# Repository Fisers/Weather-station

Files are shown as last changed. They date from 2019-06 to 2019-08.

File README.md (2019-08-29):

# Weather Station
## Included sensors
- Wind Direction (NRG #200P)
- Anenometer (NRG #40)
- Humidity (HIH8131)
- Temperature (HIH8131)
- Atmospheric pressure (BMP280)
## Interface methods
- Ethernet TCP
  - Website interface
  - TCP packets to the server
- Nokia 5110 display
- SD card data logging in CSV format
- ~~USB to UART (For debugging and programming with bootloader)~~ See issues #1
## Power supply
- 100V - 240V AC
- 3.3V DC
## Extras
- Real Time Clock
- Easy calibration using buttons
- Space Invaders minigame
- No easter eggs
## Free PINs for future upgrades
- PB0 (Timer 0) | PA3 (ADC) | PA4 (ADC) | PA5 (ADC) | PA6 (ADC) | PA7 (ADC)
- Motherboard also has free connections to 3.3v and GND aswell as SPI.

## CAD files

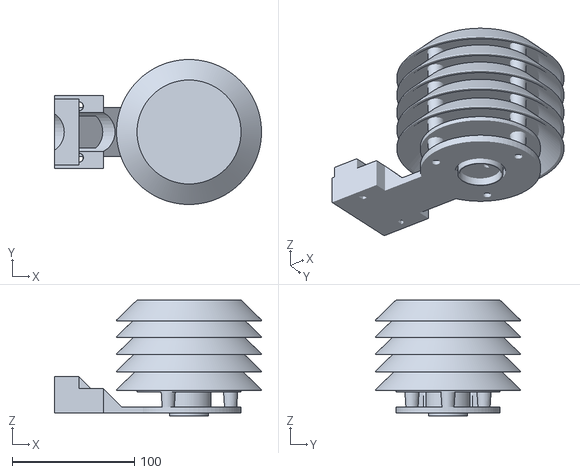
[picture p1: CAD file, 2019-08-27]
hardware/Radiation shield/Daniels_Assembled.stl
169.3 x 118.5 x 94.8

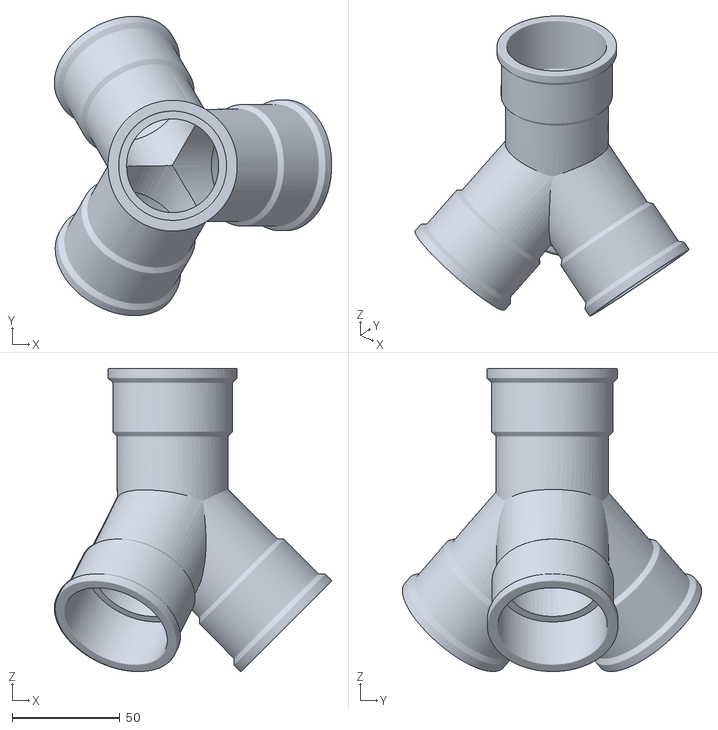
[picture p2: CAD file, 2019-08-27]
hardware/PVC tripod/tripod.stl
128.9 x 139.1 x 140.8

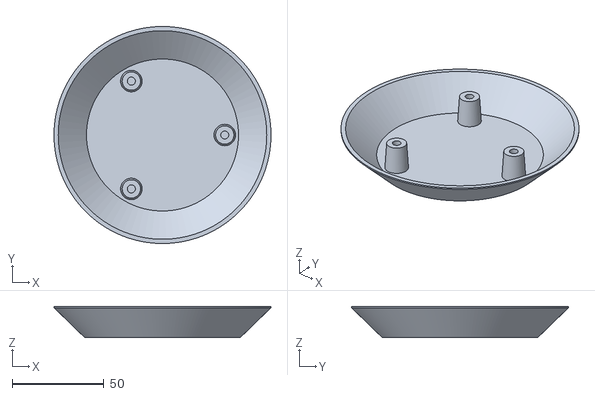
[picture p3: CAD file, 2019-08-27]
hardware/Radiation shield/Rad_Shd_Top_V1.stl
118.5 x 118.5 x 17.0

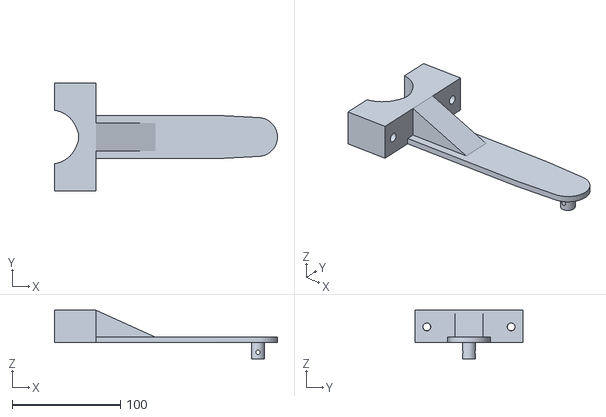
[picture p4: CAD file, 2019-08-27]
hardware/sensor mount/sensor mount.stl
206.3 x 100.0 x 45.0

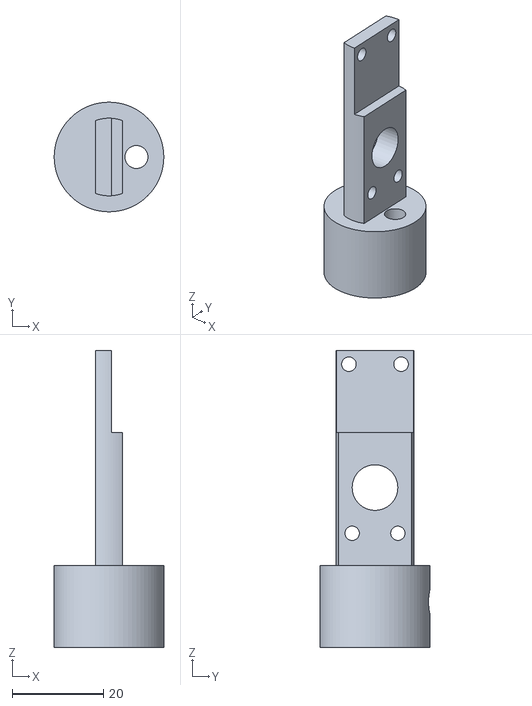
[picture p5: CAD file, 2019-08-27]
hardware/Radiation shield/HTU21D_mount_V1.stl
24.0 x 24.0 x 65.0

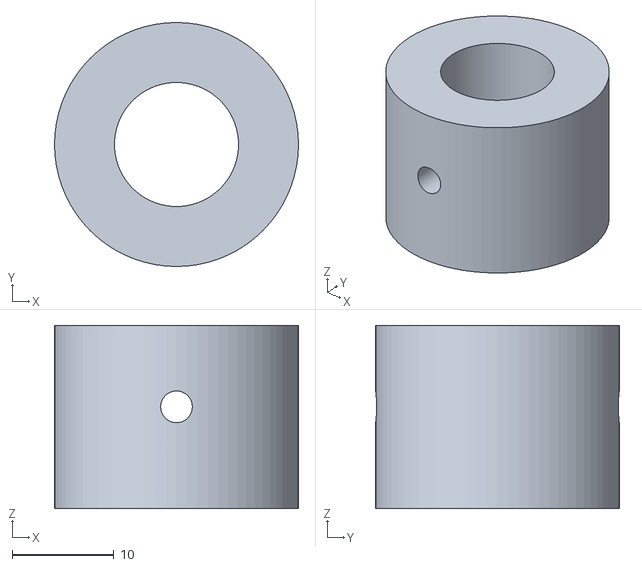
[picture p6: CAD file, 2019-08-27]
hardware/Radiation shield/HTM2500_mount_V1.stl
24.0 x 24.0 x 18.0

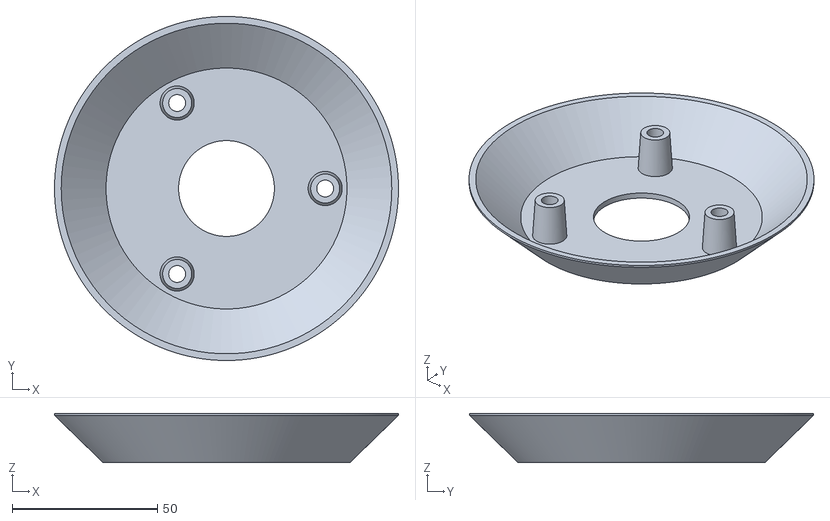
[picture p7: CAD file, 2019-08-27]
hardware/Radiation shield/Rad_Shd_Fin_V1.stl
118.5 x 118.5 x 17.0

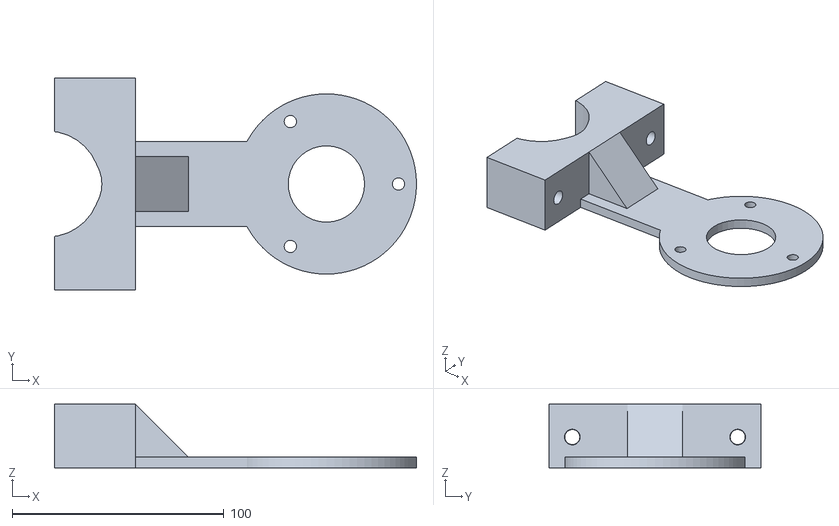
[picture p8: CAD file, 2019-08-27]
hardware/Radiation shield/Daniels_Base_Holder.stl
170.8 x 100.0 x 30.0

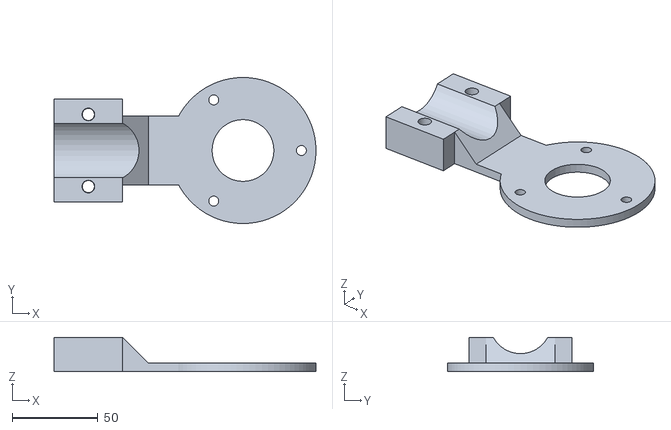
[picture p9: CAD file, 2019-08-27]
hardware/Radiation shield/Rad_Shd_Horz_mount_V1.stl
152.5 x 85.0 x 20.0

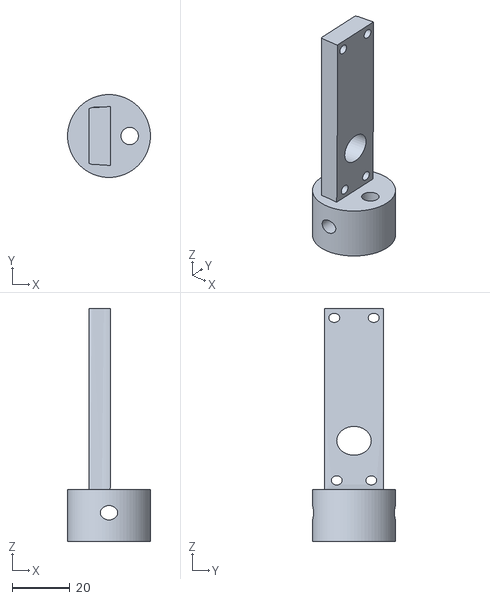
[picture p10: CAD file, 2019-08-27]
hardware/Radiation shield/Daniels_Mount.stl
28.8 x 28.8 x 81.0

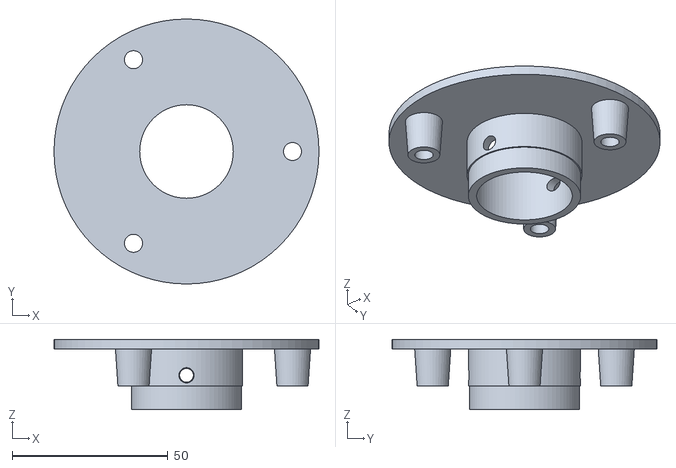
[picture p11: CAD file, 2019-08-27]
hardware/Radiation shield/Daniels_Base.stl
85.0 x 85.0 x 22.5

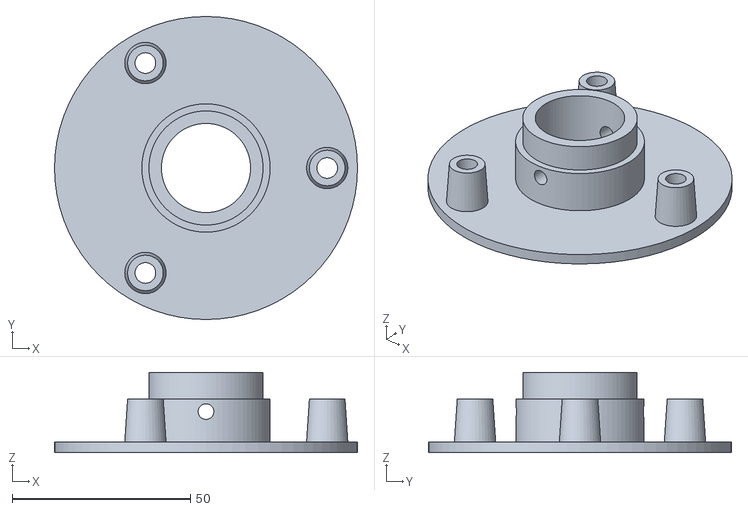
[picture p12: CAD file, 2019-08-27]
hardware/Radiation shield/Rad_Shd_Base_V1.stl
85.0 x 85.0 x 22.5

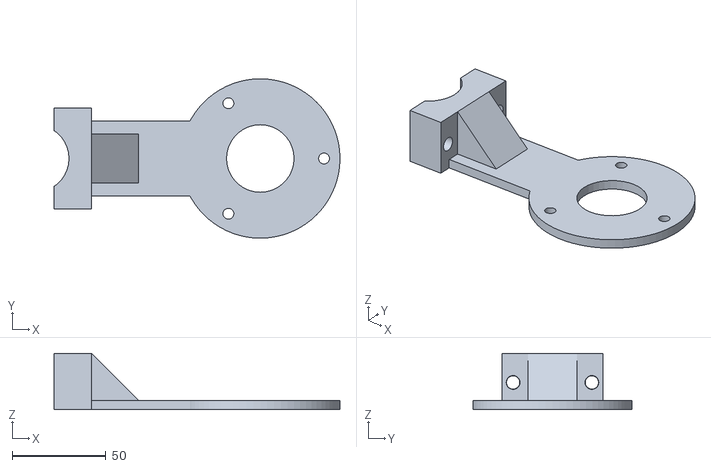
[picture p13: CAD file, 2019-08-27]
hardware/Radiation shield/Rad_Shd_Vert_mount_V1.stl
152.5 x 85.0 x 30.0

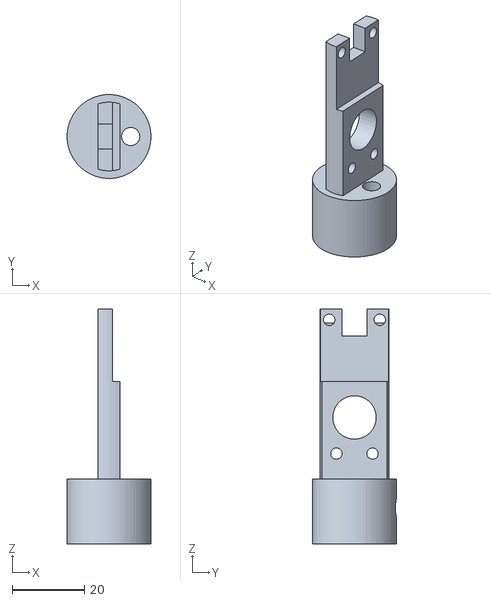
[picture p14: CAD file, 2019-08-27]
hardware/Radiation shield/SHT15_mount_V1.stl
23.2 x 23.2 x 65.0

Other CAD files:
hardware/Radiation shield/AM2315_mount_V1.stl
hardware/Radiation shield/Daniels_Base_Clamp.stl
hardware/PVC tripod/tripod.blend
hardware/Radiation shield/Radiation shield.blend
hardware/sensor mount/sensor mount.blend

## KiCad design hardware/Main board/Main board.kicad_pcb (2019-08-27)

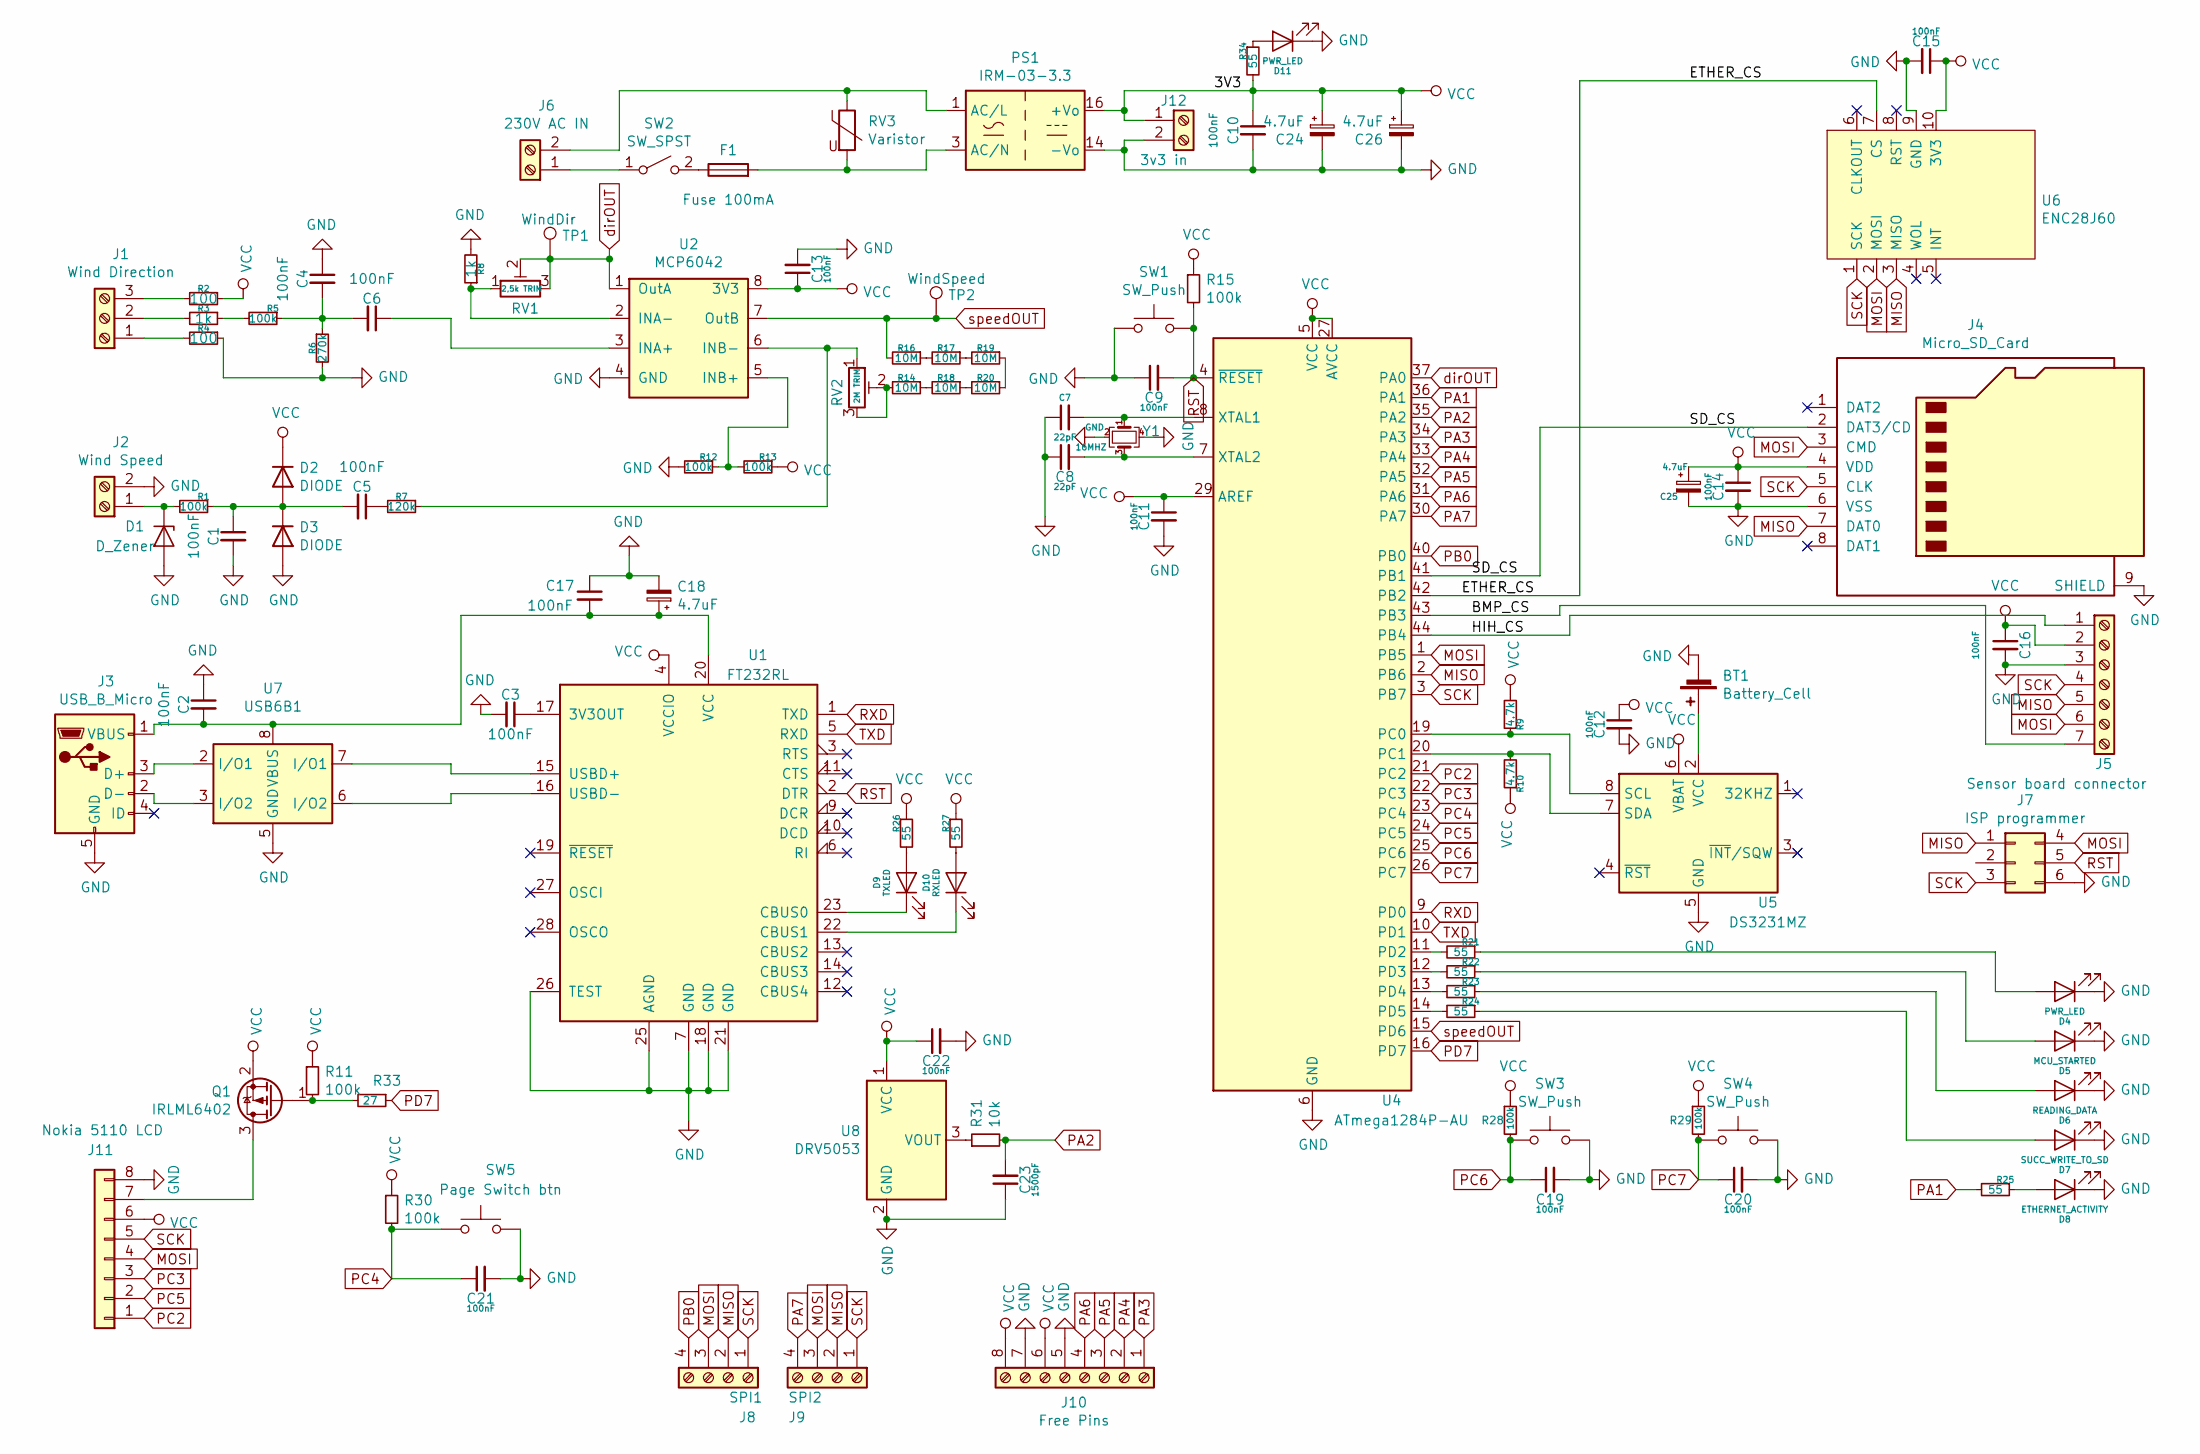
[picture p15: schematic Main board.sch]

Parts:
BT1: Battery_Cell; BatteryHolder_Keystone_106_1x20mm
C1, C2, C3, C4, C5, C6, C9, C10, C11, C12, C13, C14, C15, C16, C17, C19, C20, C21, C22: 100nF; C_0805_2012Metric_Pad1.15x1.40mm_HandSolder
C7, C8: 22pF; C_0805_2012Metric_Pad1.15x1.40mm_HandSolder
C18: 4.7uF; CP_Elec_4x5.3
C23: 1500pF; C_0805_2012Metric_Pad1.15x1.40mm_HandSolder
C24, C25, C26: 4.7uF; CP_Elec_4x5.4
D1: D_Zener; D_0805_2012Metric
D2, D3: DIODE; D_0805_2012Metric
D4, D11: PWR_LED; D_0805_2012Metric
D5: MCU_STARTED; D_0805_2012Metric
D6: READING_DATA; D_0805_2012Metric
D7: SUCC_WRITE_TO_SD; D_0805_2012Metric
D8: ETHERNET_ACTIVITY; D_0805_2012Metric
D9: TXLED; D_0805_2012Metric
D10: RXLED; D_0805_2012Metric
F1: Fuse 100mA; Fuseholder_Cylinder-5x20mm_Schurter_0031_8201_Horizontal_Op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
J1: Wind Direction; TerminalBlock_Altech_AK300-4_P5.00mm
J2: Wind Speed; TerminalBlock_Altech_AK300-2_P5.00mm
J3: USB_B_Micro; KYCON_KMMVX-SMT-BS-BTR
J4: Micro_SD_Card; microSD
J5: Sensor board connector; TerminalBlock_Phoenix_MKDS-1,5-8_1x08_P5.00mm_Horizontal
J6: 230V AC IN; TerminalBlock_RND_205-00298_1x02_P10.00mm_Horizontal
J7: ISP programmer; PinHeader_2x03_P2.54mm_Vertical
J8: SPI1; TerminalBlock_Altech_AK300-4_P5.00mm
J9: SPI2; TerminalBlock_Altech_AK300-4_P5.00mm
J10: Free Pins; TerminalBlock_Phoenix_MKDS-1,5-8_1x08_P5.00mm_Horizontal
J11: Nokia 5110 LCD; Nokia_5110_LCD
J12: 3v3 in; TerminalBlock_Altech_AK300-2_P5.00mm
PS1: IRM-03-3.3; Converter_ACDC_MeanWell_IRM-03-xx_THT
Q1: IRLML6402; SOT-23
R1, R5, R11, R12, R13, R15, R28, R29, R30: 100k; R_0805_2012Metric
R2, R4: 100; R_0805_2012Metric
R3, R8: 1k; R_0805_2012Metric
R6: 270k; R_0805_2012Metric
R7: 120k; R_0805_2012Metric
R9, R10: 4.7k; R_0805_2012Metric
R14, R16, R17, R18, R19, R20: 10M; R_0805_2012Metric
R21, R22, R23, R24, R25, R26, R27, R34: 55; R_0805_2012Metric
R31: 10k; R_0805_2012Metric
R33: 27; R_0805_2012Metric
RV1: 2,5k TRIM; Potentiometer_Bourns_3314G_Vertical
RV2: 2M TRIM; Potentiometer_Bourns_3224W_Vertical
RV3: Varistor; Varistor_SMD
SW1, SW3, SW4: SW_Push; SW_Push_1P1T_NO_6x6mm_H9.5mm
SW2: SW_SPST; Switch_NEW
SW5: Page Switch btn; SW_Push_1P1T_NO_6x6mm_H9.5mm
TP1: WindDir; Test_Pad
TP2: WindSpeed; Test_Pad
U1: FT232RL; SSOP-28_5.3x10.2mm_P0.65mm
U2: MCP6042; MCP6042-E&slash_P
U4: ATmega1284P-AU; TQFP-44_10x10mm_P0.8mm
U5: DS3231MZ; SOIC-8_3.9x4.9mm_P1.27mm
U6: ENC28J60
U7: USB6B1; SOIC-8_3.9x4.9mm_P1.27mm
U8: DRV5053; PinSocket_1x03_P2.54mm_Vertical
Y1: 16MHZ; Crystal_SMD

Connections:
/BMP_CS: J5.7, U4.43 (PB3)
/ETHER_CS: U4.42 (PB2), U6.7 (CS)
/HIH_CS: J5.1, U4.44 (PB4)
/SD_CS: J4.2 (DAT3/CD), U4.41 (PB1)
GND: BT1.2 (-), C1.2, C2.1, C3.2, C4.1, C7.1, C8.1, C9.1, C10.2, C11.2, C12.2, C13.2, C14.2, C15.2, C16.2, C17.1, C18.2, C19.2, C20.2, C21.2, C22.2, C23.1, C24.2, C25.2, C26.2, D1.2 (A), D3.1 (A), D4.1 (K), D5.1 (K), D6.1 (K), D7.1 (K), D8.1 (K), D11.1 (K), J2.2, J3.5 (GND), J4.6 (VSS), J4.9 (SHIELD), J5.3, J7.6, J10.5, J10.7, J11.8, J12.2, PS1.14 (-Vo), R4.1, R6.2, R8.2, R12.2, SW1.1, SW3.2, SW4.2, SW5.2, U1.7 (GND), U1.18 (GND), U1.21 (GND), U1.25 (AGND), U1.26 (TEST), U2.4 (GND), U4.6 (GND), U4.18 (GND), U4.28 (GND), U4.39 (GND), U5.5 (GND), U6.9 (GND), U7.4 (GND), U7.5 (GND), U8.2 (GND), Y1.2, Y1.4
MISO: J4.7 (DAT0), J5.5, J7.1, J8.2, J9.2, U4.2 (PB6), U6.3 (MISO)
MOSI: J4.3 (CMD), J5.6, J7.4, J8.3, J9.3, J11.4, U4.1 (PB5), U6.2 (MOSI)
unnamed: BT1.1 (+), U5.2 (VCC)
unnamed: C1.1, C5.2, D2.1 (A), D3.2 (K), R1.1
unnamed: C3.1, U1.17 (3V3OUT)
unnamed: C4.2, C6.2, R5.1, R6.1
unnamed: C5.1, R7.2
unnamed: C6.1, U2.3 (INA+)
unnamed: C7.2, U4.8 (XTAL1), Y1.1
unnamed: C8.2, U4.7 (XTAL2), Y1.3
unnamed: C2.2, C17.2, C18.1, J3.1 (VBUS), U1.20 (VCC), U7.1 (VBUS), U7.8 (VBUS)
unnamed: D1.1 (K), J2.1, R1.2
unnamed: D4.2 (A), R21.1
unnamed: D5.2 (A), R22.1
unnamed: D6.2 (A), R23.1
unnamed: D7.2 (A), R24.1
unnamed: D8.2 (A), R25.1
unnamed: D9.1 (K), U1.23 (CBUS0)
unnamed: D9.2 (A), R26.2
unnamed: D10.1 (K), U1.22 (CBUS1)
unnamed: D10.2 (A), R27.2
unnamed: D11.2 (A), R34.1
unnamed: F1.1, SW2.2 (B)
unnamed: F1.2, PS1.3 (AC/N), RV3.2
unnamed: J1.1, R4.2
unnamed: J1.2, R3.2
unnamed: J1.3, R2.2
unnamed: J3.2 (D-), U7.3 (I/O2)
unnamed: J3.3 (D+), U7.2 (I/O1)
unnamed: J6.1, SW2.1 (A)
unnamed: J6.2, PS1.1 (AC/L), RV3.1
unnamed: J11.7, Q1.3 (D)
unnamed: Q1.1 (G), R11.2, R33.2
unnamed: R3.1, R5.2
unnamed: R7.1, RV2.1, U2.6 (INB-)
unnamed: R8.1, RV1.1, U2.2 (INA-)
unnamed: R9.1, U4.19 (PC0), U5.8 (SCL)
unnamed: R10.2, U4.20 (PC1), U5.7 (SDA)
unnamed: R12.1, R13.2, U2.5 (INB+)
unnamed: R14.1, R18.2
unnamed: R14.2, RV2.2, RV2.3
unnamed: R16.1, R17.2
unnamed: R17.1, R19.2
unnamed: R18.1, R20.2
unnamed: R19.1, R20.1
unnamed: R21.2, U4.11 (PD2)
unnamed: R22.2, U4.12 (PD3)
unnamed: R23.2, U4.13 (PD4)
unnamed: R24.2, U4.14 (PD5)
unnamed: R31.1, U8.3 (VOUT)
unnamed: U1.15 (USBD+), U7.7 (I/O1)
unnamed: U1.16 (USBD-), U7.6 (I/O2)
PA1: R25.2, U4.36 (PA1)
PA2: C23.2, R31.2, U4.35 (PA2)
PA3: J10.1, U4.34 (PA3)
PA4: J10.2, U4.33 (PA4)
PA5: J10.3, U4.32 (PA5)
PA6: J10.4, U4.31 (PA6)
PA7: J9.4, U4.30 (PA7)
PB0: J8.4, U4.40 (PB0)
PC2: J11.1, U4.21 (PC2)
PC3: J11.3, U4.22 (PC3)
PC4: C21.1, R30.2, SW5.1, U4.23 (PC4)
PC5: J11.2, U4.24 (PC5)
PC6: C19.1, R28.2, SW3.1, U4.25 (PC6)
PC7: C20.1, R29.2, SW4.1, U4.26 (PC7)
PD7: R33.1, U4.16 (PD7)
RST: C9.2, J7.5, R15.2, SW1.2, U1.2 (DTR), U4.4 (~RESET)
RXD: U1.1 (TXD), U4.9 (PD0)
SCK: J4.5 (CLK), J5.4, J7.3, J8.1, J9.1, J11.5, U4.3 (PB7), U6.1 (SCK)
TXD: U1.5 (RXD), U4.10 (PD1)
VCC: C10.1, C11.1, C12.1, C13.1, C14.1, C15.1, C16.1, C22.1, C24.1, C25.1, C26.1, D2.2 (K), J4.4 (VDD), J5.2, J10.6, J10.8, J11.6, J12.1, PS1.16 (+Vo), Q1.2 (S), R2.1, R9.2, R10.1, R11.1, R13.1, R15.1, R26.1, R27.1, R28.1, R29.1, R30.1, R34.2, U1.4 (VCCIO), U2.8 (3V3), U4.5 (VCC), U4.17 (VCC), U4.27 (AVCC), U4.29 (AREF), U4.38 (VCC), U5.6 (VBAT), U6.10 (3V3), U8.1 (VCC)
dirOUT: RV1.2, RV1.3, TP1.1, U2.1 (OutA), U4.37 (PA0)
speedOUT: R16.2, TP2.1, U2.7 (OutB), U4.15 (PD6)

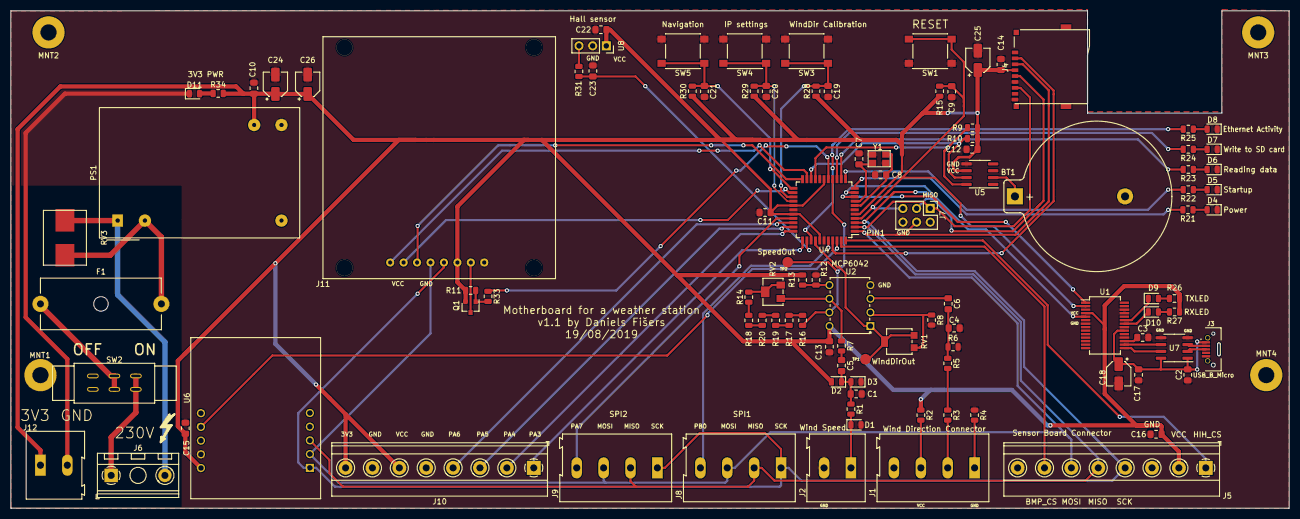
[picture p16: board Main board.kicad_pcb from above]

Board: 2 copper layers, 237.8 x 92.5 mm, 108 parts (0 on the bottom side), 79 nets.

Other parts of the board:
MNT1, MNT2, MNT3, MNT4: MountingHole_3mm_Pad

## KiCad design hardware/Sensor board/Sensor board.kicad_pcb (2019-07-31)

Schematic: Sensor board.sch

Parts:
C1, C2: C_Small; C_0805_2012Metric_Pad1.15x1.40mm_HandSolder
J1: Conn_01x07_Female; PinSocket_1x07_P2.54mm_Vertical
J2: bmp280; PinSocket_1x07_P2.54mm_Vertical
R1: R_Small; R_0805_2012Metric_Pad1.15x1.40mm_HandSolder
U1: HIH8130; SOIC-8_3.9x4.9mm_P1.27mm

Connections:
/BMP280_CS: J1.7, J2.7
/CLK: J1.4, J2.4, U1.4
/MISO: J1.5, J2.5, U1.5
/MOSI: J1.6, J2.6
GND: C1.1, C2.1, J1.3, J2.3, U1.2
unnamed: C2.2, U1.1
unnamed: J1.1, R1.2, U1.3
VCC: C1.2, J1.2, J2.2, R1.1, U1.8

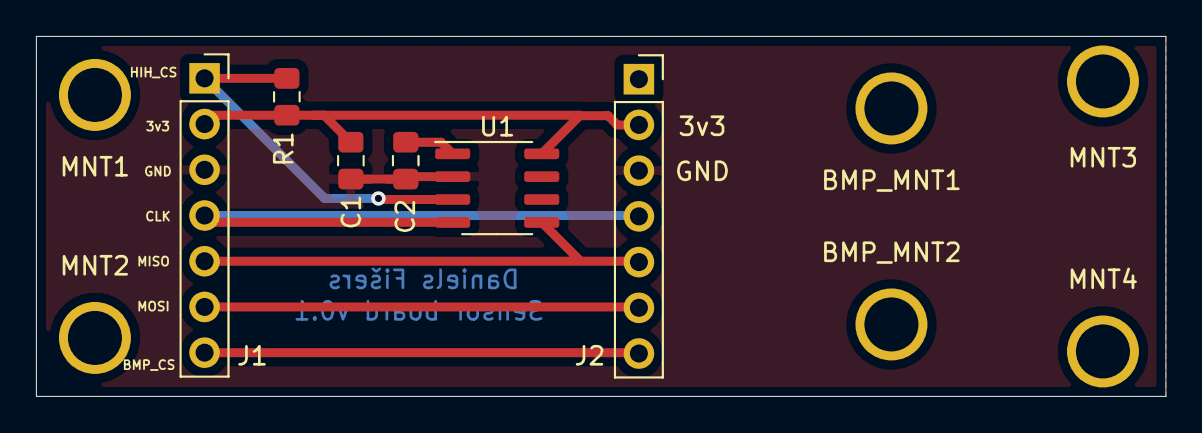
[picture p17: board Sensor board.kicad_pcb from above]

Board: 2 copper layers, 62.8 x 20.0 mm, 12 parts (0 on the bottom side), 8 nets.

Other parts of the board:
BMP_MNT1, BMP_MNT2: MountingHole_3mm_Pad
MNT1, MNT2, MNT3, MNT4: MountingHole_3mm_Pad

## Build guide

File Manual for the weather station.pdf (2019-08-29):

# Manual for the weather station

## Startup sequence

1. | 2. | 3. | 4. | 5.
All LEDs flash together to test for any bad ones. | The power LED stays on. Sensor init. | Check for any buttons pressed. | Mounting the SD card (Write to SD card LED flashes). | Connecting to the ethernet shield (Ethernet activity LED turns on while connecting).

## Calibrating wind direction ADC sensor

1. Press the WindDir Calibration button and then the RESET button.
2. Release the RESET button but keep holding the WindDir Calibration button until the display says the calibration started.
3. The display will show the current analog value, to calibrate the sensor, it has to be spun in a clockwise direction. (The value on the display should increase and startup LED blink while spinning).

## Changing Ethernet settings via serial port

1. Connect the computer to the weather station using USB and enable a serial terminal. (baud rate: 9600)
2. Press the IP settings button and then the RESET button.
3. Release the RESET button but keep holding the IP settings button until the display says the calibration started.
4. Follow instructions in the serial terminal and type IPs in format: xxx.xxx.xxx.xxx\n (example: 192.168.0.101\n)

## Web interface

- First-page displays information from sensors as well as if the box is open.
- IP settings can be changed in the settings page, as well as the port to send data to.
- The timeout (how often the data is sent) can also be changed. Timeout is the time weather station spends in the Ethernet state.
- Hall sensor value is the threshold at which it detects if the box is closed. (Try to lower the value if after closing the box it is still indicated as open, and check if the sensor is in place as well as the magnet).
- RTC Settings page is used to set the current date and time.

## Changing brightness of LCD display

To lower brightness: Hold IP Settings button and press Navigation button. To increase brightness: Hold WindDir Calibration button and press Navigation button.

## Space Invaders mode

- To start Space Invaders hold the Navigation button and WindDir Calibration button and press the RESET button. Hold them until Space Invaders splash screen appears on the display.
- Controls:
- Left - Navigation button.
- Shoot - IP Settings button.
- Right - WindDir Calibration button.
- In game mode, data won’t be collected!
- After 24 seconds of not pressing any buttons, the weather station will be reset into normal mode.

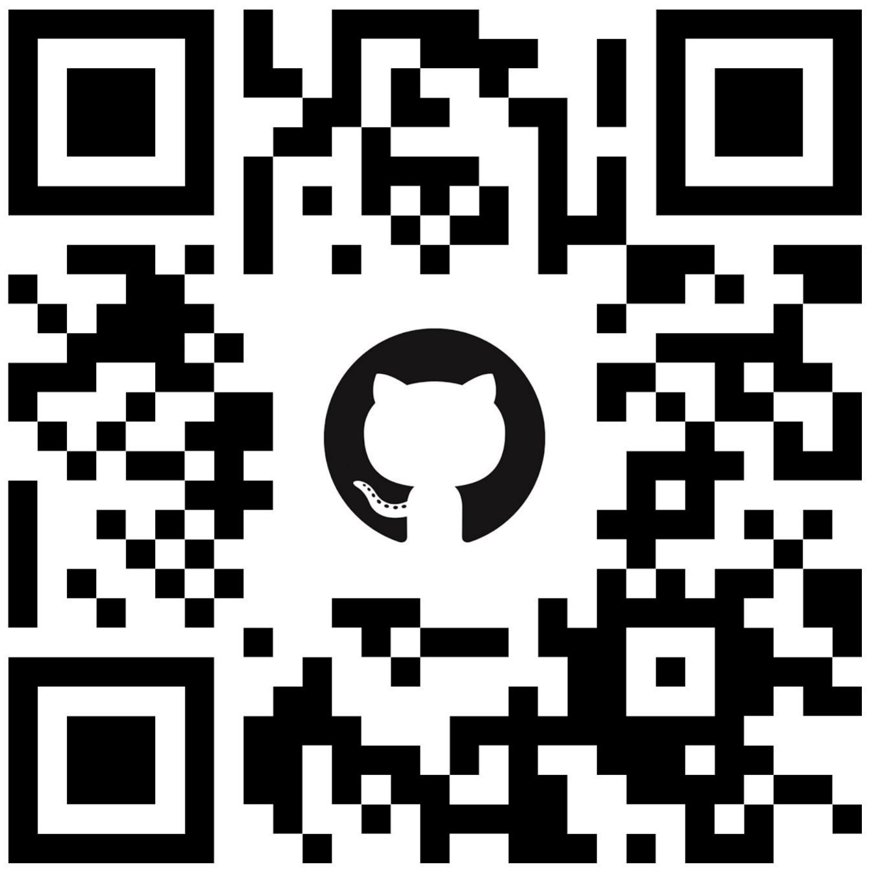
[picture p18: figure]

GitHub: https://github.com/Fisers/meteostacija | By Daniels Fišers

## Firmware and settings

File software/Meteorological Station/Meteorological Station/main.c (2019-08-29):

#define F_CPU 16000000UL // Defining the CPU Frequency for Delay Calculation in delay.h
#define BAUD 9600

#include <stdlib.h>
#include <avr/io.h> // Contains all the I/O Register Macros
#include <avr/eeprom.h>
#include <avr/pgmspace.h>
#include <avr/interrupt.h>
#include <util/delay.h> // Generates a Blocking Delay
#include <stdio.h>
#include <string.h>
#include <ctype.h>
#include "main.h"
#include <avr/wdt.h>
#include "Options.h"
#include "includes/SpaceInvaders/Space.h"



// Function Pototype
void wdt_init(void) __attribute__((naked)) __attribute__((section(".init3")));


// Function Implementation
void wdt_init(void)
{
	MCUSR = 0;
	wdt_disable();

	return;
}

// FatFs
FATFS FatFs;
FIL Fil;

UINT bw;
//
unsigned int magnetVal;
unsigned int halleff = 550;
unsigned int timeout;
rtc_t rtc;
int8_t gameMode = 0;

int brightness = 128;

static void initADC()
{
	ADCSRA |= (1 << ADEN) | (1 << ADPS2) | (1 << ADPS1) | (1 << ADPS0);
	ADMUX |= (1 << REFS0) | (1 << MUX1);
}

#define REF_AVCC (1<<REFS0)  // reference = AVCC = 3.3 V
uint16_t adc_read(uint8_t channel)
{
	ADMUX = REF_AVCC | channel;  // set reference and channel
	ADCSRA |= (1<<ADSC);         // start conversion
	while(ADCSRA & (1<<ADSC)); // wait for conversion complete
	return ADC;
}

int16_t LargestDirectionValue;
static void calibration()
{
	printf_P(PSTR("Calibration started!\n"));
	lcd_setXY(0x40,0x80);
	N5110_Data("Calibration");
 	lcd_setXY(0x41,0x80);
 	N5110_Data("Started");
	while(adc_read(0)+50 >= LargestDirectionValue)
	{
		wdt_reset();
		if(adc_read(0) > LargestDirectionValue)
		{
			PORTD |= (1 << PIND3);
			LargestDirectionValue = adc_read(0);
			dtostrf(LargestDirectionValue,1,2,pressChar);
			lcd_setXY(0x43,0x80);
			N5110_Data(pressChar);
		}
		_delay_us(250);
		PORTD &= ~(1 << PIND3);
	}
	eeprom_write_float(0x00, LargestDirectionValue);
	printf_P(PSTR("Calibration complete!\n"));
}

void stringToIntArray(uint8_t * array, char * string, uint8_t * eepromAddr)
{
	uint8_t i = 0;
	char * p = string;
	while(*p) {
		if ( isdigit(*p) || ( (*p=='-'||*p=='+') && isdigit(*(p+1)) )) {
			array[i] = strtol(p, &p, 10);
			eeprom_write_byte((uint8_t*)eepromAddr+i, array[i]);
			i++;
			} else {
			p++;
		}
	}
}

static void getInput(char *input)
{
	char c;
	uint8_t i;
	for(i = 0; i < 16; i++) {
		c = getchar();
		if (c == '\n') break;
		input[i] = c;
	}
	input[i] = '\0';
}

static void ipconfig()
{
	static char input[16];
	
	lcd_setXY(0x40,0x80);
	N5110_Data("Calibration");
	lcd_setXY(0x41,0x80);
	N5110_Data("Started");

	puts("Input arduino IP");
	getInput(input);
	printf("Arduino IP: %s\n", input);
	stringToIntArray(myip, input, (uint8_t*)0x20);
	
	puts("Input server IP");
	getInput(input);
	printf("Server IP: %s\n", input);
	sprintf(serverip, "%s", input);
	eeprom_write_block((const void*)input, (void*)0x30, 16);
	
	puts("Input gateway IP");
	getInput(input);
	printf("Gateway IP: %s\n", input);
	stringToIntArray(gwip, input, (uint8_t*)0x40);
}

char packetStr[128];
uint8_t runOnce = 0;
char humidChar[10],tempChar[10],pressChar[16],anglChar[10],speedChar[10];
int page = 1;

ISR(PCINT2_vect)
{
	if((PINC&(1 << PINC4)) == 0)
	{
		if((PINC&(1 << PINC7)) == 0)
		{
			if(brightness + 25 > 255)
			{
				brightness = 255;
			}
			else
			{
				brightness += 25;
			}
		}
		else if((PINC&(1 << PINC6)) == 0)
		{
			if(brightness - 25 < 0)
			{
				brightness = 0;
			}
			else
			{
				brightness -= 25;
			}
		}
		else
		{
			page++;
			if(page >= 4) page = 1;
		
			printPage(page);
		}
		OCR2A = brightness;
		TCCR2A |= (1 << COM2A1);
		TCCR2A |= (1 << WGM21) | (1 << WGM20);
		TCCR2B |= (1 << CS21);
	}
}

int main(void)
{	
	// init arrays
	//memset(bullets, 0, 32);
	//
 	DDRD = 0b10111100;
 	DDRA |= (1 << PINA1);
	PORTA |= (1 << PINA1);
	PORTD = 0b00111100;
	_delay_ms(500);
 	PORTD &= 0b11000111;
 	PORTA &= ~(1 << PINA1);
	PORTD &= ~(1 << PIND5);
	
	
	
 	

// 	uart_init();
// 	stdout = &uart_output;
// 	stdin  = &uart_input;
// 	puts_P(PSTR("Initializing"));
 	DDRC |= (0 << PINC6);
 	PORTC |= (1 << PINC6);
	DDRC |= (0 << PINC7);
	PORTC |= (1 << PINC7);
	DDRC |= (0 << PINC4);
	PORTC |= (1 << PINC4);
	
	 DDRD |= (1 << DDD7);
	 // PD6 is now an output

	 OCR2A = brightness;
	 // set PWM for 50% duty cycle


	 TCCR2A |= (1 << COM2A1);
	 // set none-inverting mode

	 TCCR2A |= (1 << WGM21) | (1 << WGM20);
	 // set fast PWM Mode

	 TCCR2B |= (1 << CS21);
	 // set prescaler to 8 and starts PWM
	 
	spi_init_master();
 	N5110_init();
	N5110_clear();
	
	DDRD |= (1 << PIND7);
	if((PINC&(1 << PINC4)) == 0 && (PINC&(1 << PINC6)) == 0) // Check for both calibration buttons pressed
	{
		SpaceStart();
	}
	
	wdt_reset();
	wdt_enable(WDTO_2S);
		
	DDRB |= (1 << SD_CS);
	PORT_CS |= (1<<HIH_CS);
	PORT_CS |= (1<<BMP_CS);
	PORT_CS |= (1<<SD_CS);
 	i2c_init();
 	bmp280_init();
	wind_initWindSpeed();
	initADC();
		
	// Read IP values from eeprom
		for(uint8_t i = 0; i<4; i++)
		{
			uint8_t temp;
			temp = eeprom_read_byte((uint8_t*)0x20+i);
			if(temp == 255)	break;
			myip[i] = eeprom_read_byte((uint8_t*)0x20+i);
			gwip[i] = eeprom_read_byte((uint8_t*)0x40+i);
		}
		eeprom_read_block((void*)serverip, (const void*)0x30, 16);
	//
	halleff = eeprom_read_word((const void*)0x60);

	// calibration
	wdt_reset();
	if((PINC&(1 << PINC6)) == 0)
	{
		calibration();
	}
	else {
		LargestDirectionValue = eeprom_read_float(0x00);
	}
	
		if((PINC&(1 << PINC7)) == 0)
		{
			wdt_disable();
			ipconfig();
			wdt_reset();
			wdt_enable(WDTO_2S);
		}
// 		//
 	timeout = eeprom_read_word((uint16_t*)0x10);
	wdt_reset();
	PORTD |= (1 << PIND5);
	PORT_CS &= ~(1<<SD_CS);
	f_mount(&FatFs, "", 0);
	PORT_CS |= (1<<SD_CS);
	PORTD &= ~(1 << PIND5);

	wdt_reset();
 	wdt_disable();
	PORTA |= (1 << PINA1);
	PORTB |= (1 << ETHER_CS);
	Ether_init();
	PORTA &= ~(1 << PINA1);
 	wdt_reset();
 	wdt_enable(WDTO_2S);
		
	DDRC |= (0 << PINC4);
	PORTC |= (1 << PINC4);
	 
	PCMSK2 |= (1 << PCINT20);
	PCICR |= (1 << PCIE2);
	 	
	sei();
	PORTD |= (1 << PIND3);
	while(1) {	
		float wind_speed;
		

		if(sendingPacket == 1)
		{
			PORTA |= (1 << PINA1);
			Ether_SendPacket(packetStr);
			continue;
		}
		PORTA &= ~(1<<PINA1);
		wdt_reset();
		wdt_enable(WDTO_2S);
		PORTD |= (1 << PIND4);
		if(runOnce == 0) {
			flag =0;
			TIFR1=(1<<ICF1);
			runOnce = 1;
			sec = 0;
		}
		if(flag < 2 && sec < 2) {
			continue;
		}
		runOnce = 0;

		wdt_reset();
		//wind_speed = 0.765 * wind_measureFrequency() + 0.35;
		wind_speed = wind_measureFrequency();
		if(wind_speed < 0 || wind_speed > 1000)
			wind_speed = 0;
		
		magnetVal = adc_read(2);

		if(magnetVal < halleff)
		{
			OCR2A = brightness;
			TCCR2A |= (1 << COM2A1);
			TCCR2A |= (1 << WGM21) | (1 << WGM20);
			TCCR2B |= (1 << CS21);
		}
		else
		{
			OCR2A = 255;
			TCCR2A |= (1 << COM2A1);
			TCCR2A |= (1 << WGM21) | (1 << WGM20);
			TCCR2B |= (1 << CS21);
		}
		
 		RTC_GetDateTime(&rtc);

		wdt_reset();
		
		float angle = ((float)adc_read(0) / (float)LargestDirectionValue) * 360.0;
		if(angle > 360)
			angle = 360;
		
		hih8120_measure();
		dtostrf(hih8120_humidity,1,2,humidChar);
		dtostrf(hih8120_temperature_C,1,2,tempChar);
		
		printf("%s\n", humidChar);
		printf("%s C\n", tempChar);
 		dtostrf(bmp280_readPressure(),1,2,pressChar);
		printf("%s Pa\n", pressChar);
		 
		
		printf("%s Pa", pressChar);
		dtostrf(angle,1,2,anglChar);
		dtostrf(wind_speed,1,2,speedChar);
		sprintf(packetStr, "%02d:%02d:%02d,%s,%s,%s,%s,%s", rtc.hour, rtc.min, rtc.sec,tempChar, humidChar, pressChar, anglChar, speedChar);
		printPage(page);
		
		wdt_reset();
		
		PORTD &= ~(1<<PIND4);
 		PORTD |= (1 << PIND5);
		char fileName[16];
		sprintf(fileName, "%02d-%02d-%02d.CSV", rtc.date, rtc.month, rtc.year);

		if(f_open(&Fil, fileName, FA_WRITE) == FR_OK)
		{
			f_lseek(&Fil, Fil.fsize);
			char sdData[snprintf(NULL,0,"%02d:%02d:%02d,%s,%s,%s,%s,%s\r\n", rtc.hour, rtc.min, rtc.sec, pressChar, anglChar, speedChar, humidChar, tempChar)];
			sprintf(sdData, "%02d:%02d:%02d,%s,%s,%s,%s,%s\r\n", rtc.hour, rtc.min, rtc.sec, pressChar, anglChar, speedChar, humidChar, tempChar);
			f_write(&Fil, sdData, sizeof(sdData), &bw);	// Write Data to the file
			f_close(&Fil);
		}
		else
		{
			if (f_open(&Fil, fileName, FA_WRITE | FA_CREATE_ALWAYS) == FR_OK) {	/* Create a file */
				f_write(&Fil, "Time,Pressure,Wind Angle,Wind Speed,Humidity,Temperature\r\n", 58, &bw);	// Create CSV header
				f_close(&Fil);								/* Close the file */
			}
		}
 		PORTD &= ~(1<<PIND5);
// 		_delay_ms(1000);
		
 		wdt_reset();
 		wdt_disable();
// 		
		PORTA |= (1 << PINA1);
		sec = 0;
		Ether_SendPacket(packetStr);
	}
	
	return 0;
}

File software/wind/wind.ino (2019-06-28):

#include <EEPROM.h>

// Calibration
int LargestDirectionValue;
// Wind speed
#define MainPeriod 450
long previousMillis = 0;
volatile unsigned long duration=0;
volatile unsigned int pulsecount=0;
volatile unsigned long previousMicros=0;
///////////////////////

void calibration()
{
  Serial.println("Calibration started!");
  while(analogRead(A0)+10 >= LargestDirectionValue)
  {
    if(LargestDirectionValue < analogRead(A0))
    {
      LargestDirectionValue = analogRead(A0);
    }
    delayMicroseconds(250);
  }
  EEPROM.write(0, LargestDirectionValue & 0xFF);
  EEPROM.write(1, LargestDirectionValue >> 8);
  Serial.println("Calibrated!");
}

void setup() {
  Serial.begin(9600);
  pinMode(7, INPUT);
  if(digitalRead(7) == HIGH)
  {
    calibration();
  }
  attachInterrupt(digitalPinToInterrupt(2), windFreqDuration, RISING);

  LargestDirectionValue = EEPROM.read(1);
  LargestDirectionValue <<= 8;
  LargestDirectionValue |= EEPROM.read(0);
}

String AngleToDirection(float grdi)
{
  if(grdi >= 348.75 or grdi <= 11.25)
  {
    return "North";
  }
  else if(grdi >= 78.75 and grdi <= 101.25)
  {
    return "East";
  }
  else if(grdi >= 168.75 and grdi <= 191.25)
  {
    return "South";
  }
  else if(grdi >= 258.75 and grdi <= 281.25)
  {
    return "West";
  }
  else
  {
    return "";
  }
}

void loop() {
  
  // Wind direction measure //
  
  int value = analogRead(A0);
  float angle = ((float)value / (float)LargestDirectionValue) * 360.0;
  
  // Wind speed measure //
  
  unsigned long currentMillis = millis();
  if (currentMillis - previousMillis >= MainPeriod) 
  {
    noInterrupts();
    previousMillis = currentMillis;   
    unsigned long _duration = duration;
    unsigned long _pulsecount = pulsecount;
    duration = 0;
    pulsecount = 0;
    float Freq = 1000000 / float(_duration);
    Freq *= _pulsecount; // calculate F

    float windSpeed = 0.765 * Freq + 0.35;
    Serial.print("Direction");
    Serial.print(" ");
    Serial.print("Angle");
    Serial.print(" ");
    Serial.println("Speed");
    Serial.print(AngleToDirection(angle));
    Serial.print("    ");
    Serial.print(angle);
    Serial.print(" ");
    Serial.print(windSpeed);
    Serial.println("m/s");
    interrupts();
  }
  
  delay(250);
}

void windFreqDuration()
{
  duration += micros() - previousMicros;
  previousMicros = micros();
  pulsecount++;
}

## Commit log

2019-06-28 Convert SIP-4 to 2.54mm for use in breadboard
    [Sip-4 To 2.54mm.kicad_pcb, Sip-4 To 2.54mm.sch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]
2019-06-28 Arduino code for measuring wind speed and direction
2019-07-05 AVR version for wind direction and atmospheric pressure
2019-07-17 Sensor board for HIH8131 and BMP280 for use in a radiation shield.
    [Sensor board.kicad_pcb, Sensor board.sch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]
2019-07-19 Added main board.
    [Main board.sch]
2019-07-19 Added a main board schematic
    [Main board.sch]
2019-07-22 Updated the board with nokia 5110 display.
    [Main board.sch]
2019-07-23 Finished the schematic for the main board
    [Main board.kicad_pcb, Main board.sch]
2019-07-23 Updated main board
    [Main board.kicad_pcb, Main board.sch]
2019-07-24 Finished the board design
    [Main board.kicad_pcb, Main board.sch]
2019-07-25 Added 0 new easter eggs
    [Main board.kicad_pcb, Main board.sch]
2019-07-26 Improved the design of the PCB
    [Main board.kicad_pcb]
2019-07-26 Updated the main board to v0.5
    [Main board.kicad_pcb, Main board.sch]
2019-07-26 Main board update
    [Main board.kicad_pcb]
2019-07-26 Minor update to the main board
    [Main board.kicad_pcb]
2019-07-26 Added button labels
    [Main board.kicad_pcb]
2019-07-29 Added protection for power input
    [Main board.kicad_pcb, Main board.sch]
2019-07-29 Updated the power supply input
    [Main board.kicad_pcb, Main board.sch]
2019-07-29 Changed varistor footprint
    [Main board.kicad_pcb]
2019-07-30 Updated the footprint to fit radiation shield
    [Sensor board.kicad_pcb]
2019-07-31 Changed a few pins
    [Main board.kicad_pcb, Main board.sch]
2019-07-31 Slight improvements to the board
    [Main board-B_Cu.gbr, Main board-B_Mask.gbr, Main board-B_SilkS.gbr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]
2019-07-31 Slight adjustments
    [Main board.kicad_pcb]
2019-08-14 Fixed multiple things
    [Main board-B_Cu.gbr, Main board-B_Mask.gbr, Main board-B_SilkS.gbr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]
2019-08-19 Fixed multiple issues
    [Main board.kicad_pcb]
2019-08-27 Added new 3D models
    [AM2315_mount_V1.stl, Daniels_Assembled.stl, Daniels_Base.stl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]
2019-08-27 Motherboard version v1.1
    [Main board-B_Cu.gbr, Main board-B_Mask.gbr, Main board-B_SilkS.gbr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]

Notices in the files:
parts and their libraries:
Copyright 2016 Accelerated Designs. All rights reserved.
